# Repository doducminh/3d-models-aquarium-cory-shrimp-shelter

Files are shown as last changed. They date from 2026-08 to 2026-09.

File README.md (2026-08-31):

# Hang trú ẩn cho cá chuột — nửa hang áp mặt kính

Một **nửa hang động** áp thẳng vào mặt kính hồ. Mặt kính làm "thành thứ tư" của
hang, nên nhìn qua kính thấy đúng một mặt cắt hang động — và thấy con cá đang
làm gì bên trong. Toàn thân chôn dưới nền, chỉ **cửa hang và chỏm đá** nhô lên.

In bằng **PETG** (ngâm nước lâu dài; PLA thuỷ phân, giòn dần theo tháng).
**Không một cọng support** — đó là hệ quả hình học, không phải may: toàn vật mô
tả bằng hai trường độ sâu, mặt đá ngoài luôn hướng lên, còn trần hang dựng bằng
hàm khoảng cách nên nghiêng đúng 42° ở mọi chỗ.

> ### Khe hở giữa thân hang và khung mỏng hơn thiết kế — 0,3 mm chứ không phải 2,0
>
> Thiết kế khai khe nhấc **2,0 mm**. Đo lại trên chính sáu file STL trong repo,
> ở đúng tư thế lắp, thì chỗ hẹp nhất chỉ còn:
>
> | bộ | khe thật, chỗ hẹp nhất |
> |---|---|
> | `goc-be-trai/` | +0,61 mm |
> | `goc-be-phai/` | +0,33 mm |
> | `doc-kinh-truoc/` | **−0,18 mm** (17 trên 19 336 đỉnh chạm nhẹ) |
>
> **Cả hai bộ đã in thật và lắp được** — thả thân hang từ trên xuống vào lòng
> khung không cần lực. Nên đây không phải lỗi chặn in, mà là **biên an toàn mỏng
> hơn bảng số nói**: nếu máy bạn in hơi phồng, hoặc bạn in PETG co ngót nhiều,
> thì bộ `doc-kinh-truoc` có thể phải rà nhẹ mép trước khi lắp.
>
> (Bản cảnh báo trước ở chỗ này nói bộ STL "không lắp được" và ghi 208 mm³ đâm
> nhau — số đó đo bằng phép biến đổi lắp sai, đã dựng lại phép đo và không tái
> hiện được; xem HANDOFF điểm mù 96.)

**[Xem mô hình 3D →](viewer/index.html)**

---

## Chọn MỘT thư mục, in CẢ thư mục

Mỗi thư mục là một **bộ hoàn chỉnh**: một thân hang + một khung chắn đất.

| thư mục | đặt ở đâu | thân hang | khung chắn đất | cả bộ |
|---|---|---|---|---|
| **`doc-kinh-truoc/`** | giữa mặt kính trước | 114 × 70 × 48 mm · 41 g · 4h04 | 127 × 60 × 35 mm · 33 g · 3h20 | 74 g · 7h24 |
| **`goc-be-phai/`** | góc bể bên phải, nhìn được từ **hai** mặt kính | 100 × 71 × 48 mm · 33 g · 3h30 | 107 × 60 × 35 mm · 24 g · 2h17 | 57 g · 5h47 |
| **`goc-be-trai/`** | góc bể bên trái, nhìn được từ **hai** mặt kính | 100 × 71 × 48 mm · 33 g · 3h31 | 107 × 60 × 35 mm · 24 g · 2h17 | 57 g · 5h48 |

Bộ góc trái là **ảnh gương** của bộ góc phải — hộp bao trùng khớp tới 0,01 mm ở
cả ba chiều. Chọn theo góc bể bạn định đặt, đừng in cả hai rồi lật.

> **Đừng trộn các thư mục với nhau.** Lòng khung suy ra từ *vết quét* của chính cái thân
> hang cùng bộ; ghép khung của bộ này với thân của bộ kia thì khe nhấc sai và
> hang không rút lên được. Chép **cả thư mục** sang USB là chắc nhất.

`.gcode` slice sẵn cho Elegoo Neptune 4 nằm trong `gcode/<cùng tên thư mục>/`.
`.3mf` đi kèm để mở lại sửa tại chỗ nếu tới nơi mới phát hiện phải chỉnh.

---

## Hai bộ phận làm gì

**Thân hang** — cái hang. In **úp mặt áp kính xuống bàn**; lớp đầu chính là mặt
cắt hang mà người xem nhìn thấy, nên hiệu chuẩn z-offset trước khi in bản thật.

**Khung chắn đất** — một vách mỏng chôn sẵn trong nền, ôm dáng ngầm của hang. Nó
**ở lại** khi nhấc hang lên vệ sinh, nên hạt nền không đổ ập vào chỗ trống. In
**đứng**, vành chân là lớp đầu. Từ bản này nó gánh thêm việc thứ hai: làm **vách
sau** của hang, nhờ đó bụng hang thông suốt và chỗ nằm cho cá rộng gấp 2,6 lần.

### Vành chân là một MÁNG DẰN — phải đổ sỏi vào

Vành chân không phải một tấm phẳng: nó là **máng hở nóc, sâu 18 mm**, chạy dọc
mặt ngoài khung, có một hàng lỗ để nền hai bên nối liền qua.

Lý do nó tồn tại là một con số. Khung nặng 24 g khô, nhưng PETG chỉ nặng hơn nước
27% nên **dưới nước nó chỉ còn 5 gf** — bản đầu tiên đã đổ thật trong hồ, và tính
ra chỉ cần **0,36 gf** đẩy ngang là lật. Nới vành chân rộng ra không cứu được:
cánh tay đòn vốn đã đủ, thứ gần bằng không là **trọng lượng**. Đổ đầy sỏi/nền vào
máng thì lực giữ lên **13 gf**, gấp ba, và trọng tâm hạ từ 15,3 xuống 12,3 mm.

Máng nằm **hoàn toàn bên trong** hình bao cũ — bề sâu vẫn đúng 59,8 mm như bản đã
in vừa chỗ, không phải đo lại gì.

## Cài đặt in

Vòi **0,4** · lớp **0,2** · **PETG** · **không support** (đo được 0% trong cả sáu
file gcode) · **brim 5 mm** cho cả hai chi tiết — đã khai sẵn trong `.gcode`.

Brim không phải cho chắc ăn thừa. Thân hang có lớp đầu là một **vành rộng 9 mm,
chu vi ~330 mm**: nó không chênh vênh và không lật, nó **bong mép** — mà mép ấy
chính là mặt người xem nhìn vào. Khung thì là một bức tường cao gấp 12 lần bề dày,
dài hơn 200 mm, cong vênh theo chiều dài khi PETG co ngót.

Cả hai chi tiết **đã ở đúng tư thế in trong file** — đừng để slicer tự xoay, và
đừng in hai chi tiết cùng một tư thế.

## Lắp

1. **Rải một lớp nền mỏng xuống trước**, rồi mới đặt khung và ấn cho vành chân
   lún vào. Đặt khung lên mặt kính trơn thì nó chưa có gì giữ.
2. **Đổ sỏi/nền đầy máng dằn** ở vành chân — đây là bước dễ quên nhất và là bước
   quyết định khung có đứng vững không.
3. Lấp nền quanh khung, ngoài khung, cho ngập qua máng.
4. Thả **thân hang** thẳng từ trên xuống vào lòng khung — khe hở 2 mm, không cần lực.
5. Vun nền cho ngập tới chân cửa hang; ngưỡng cửa cao hơn mặt nền 6 mm nên hạt
   không tràn vào.

**Lúc nhấc hang ra vệ sinh:** giữ một tay lên mép khung, tay kia rút hang thẳng
lên. Ma sát khi hang trượt qua khe 2 mm là đủ để kéo theo cả cái khung.

Ngâm nước **48 giờ** xả mùi trước khi thả vào hồ đang có cá.

---

## Xem trước

`viewer/index.html` — mở thẳng bằng trình duyệt, không cần máy chủ web. Trang
dựng hình bằng JS nên chỉnh được kiểu hang, hướng cửa, cỡ in… và xem số đo đổi
theo ngay.

## Cửa hang KHÔNG chặn được cá lớn — đo rồi, và nó là giới hạn cứng

Nếu bạn định dùng hang này để cá nhỏ trốn một con cá lớn hơn, đọc mục này trước.

Cửa cao 22,4 mm. Nó **không** hạ xuống được bao nhiêu, vì chính con cá chuột đặt
ra sàn: thân nó cao 14,4 mm và phải có 2 mm khe mỗi bên — gai ngực nó **khoá lại
khi hoảng**, kẹt cửa là chết cá. Sàn cứng vì thế là **18,4 mm**, và toàn bộ chỗ
co giãn của cửa chỉ là 22,4 → 18,9 mm.

Con betta trong hồ thử nghiệm đo được **cao thân 15,0 mm** (cụp vây). Nó mỏng hơn
cả cái sàn 18,4 mm, nên **không tồn tại cái cửa nào vừa cho cá chuột qua vừa chặn
nó** — hai loài chỉ cách nhau 0,6 mm bề cao thân. Thu nhỏ cửa là ngõ cụt, không
phải chuyện tinh chỉnh.

Muốn chặn thì phải chặn bằng **hình thái cửa** chứ không phải cỡ cửa: cá chuột là
cá đáy, chui khe là bản năng; cá tầng giữa vây dài thì tránh ống dài tối có khúc
quẹo. Viewer có sẵn bốn kiểu cửa để xem — `sau` (rèm đá che), `ben` (khe ngang
xuyên sườn), `duoi` (cửa quay xuống nền). **Các file STL ở đây đều là kiểu `kinh`
(cửa nhìn thẳng), tức KHÔNG có hàng rào nào.**

## Trạng thái

✅ **Đã in thật bộ `doc-kinh-truoc/` và bộ `goc-be-phai/`** — lắp vào hồ đạt, chủ
dự án nghiệm thu ổn. Đó là hai bộ đã đi hết vòng: thiết kế → in → ướm vào chỗ thật.

⚠️ **Khung của cả ba bộ đã được dựng lại** sau khi bản in đầu **đổ trong hồ**: vành
chân giờ là máng dằn (mục trên). Thân hang **không đổi một milimét nào** — file
`than-hang.stl` của bạn vẫn dùng được, chỉ cần in lại `khung-chan-dat.stl`.
Máng dằn thì mới, **chưa qua bản in thật**.

⚠️ Bộ `goc-be-trai/` **chưa in** — nhưng nó là ảnh gương đúng nghĩa của bộ góc
phải đã in đạt, dựng từ cùng bộ script, cùng cỡ, cùng seed.

Bảng số trong README này là số đo trên mô hình và trên gcode, không phải cân đo
vật in ra; lệch vài phần trăm khối lượng là bình thường.

---

## Bản quyền

Cả sáu file đều mang dấu **`doducminh`** khắc chìm trên vật. Trên thân hang
dấu nằm ở mặt áp kính và khắc **soi gương** — đọc đúng chiều khi nhìn từ ngoài
hồ vào.

Giấy phép: **CC BY-NC-SA 4.0** cho file thiết kế.

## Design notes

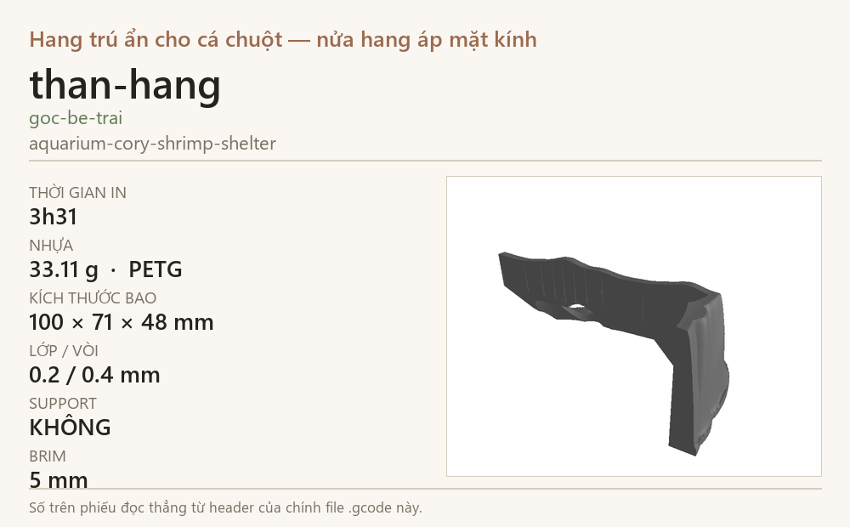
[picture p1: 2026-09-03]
gcode/goc-be-trai/than-hang.png

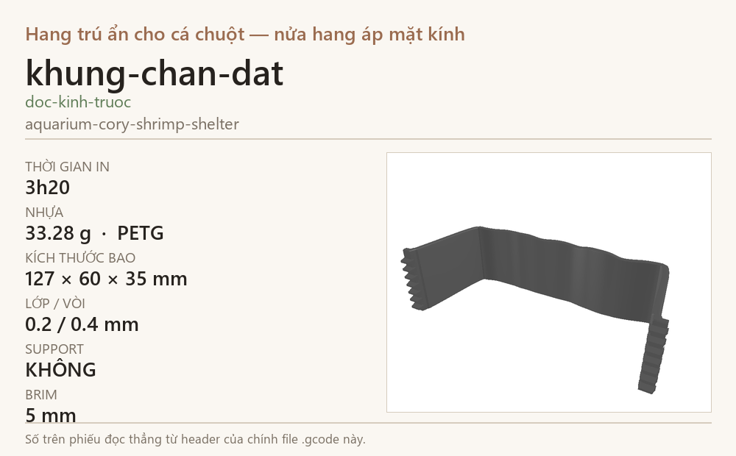
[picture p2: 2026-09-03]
gcode/doc-kinh-truoc/khung-chan-dat.png

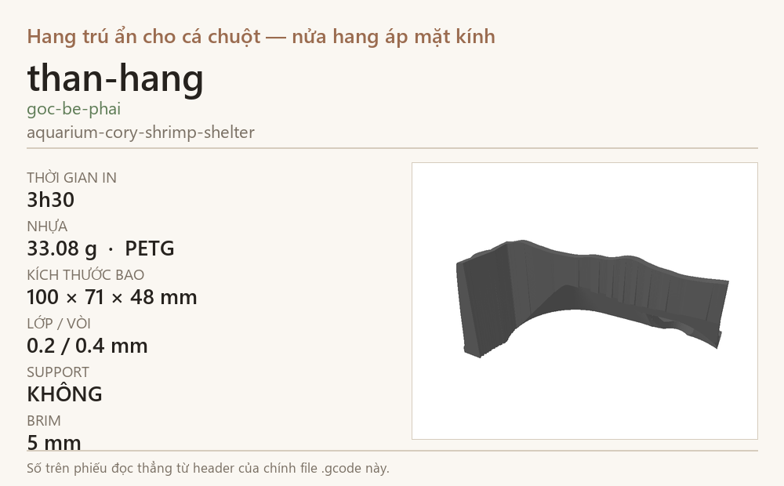
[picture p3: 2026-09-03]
gcode/goc-be-phai/than-hang.png

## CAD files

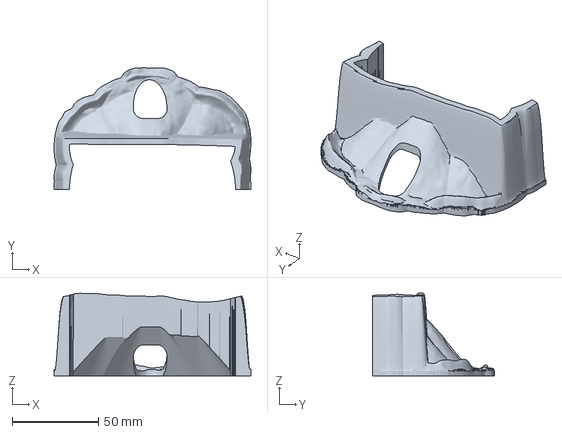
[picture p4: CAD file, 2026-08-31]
gcode/doc-kinh-truoc/than-hang.3mf
114.0 x 70.3 x 47.8 mm

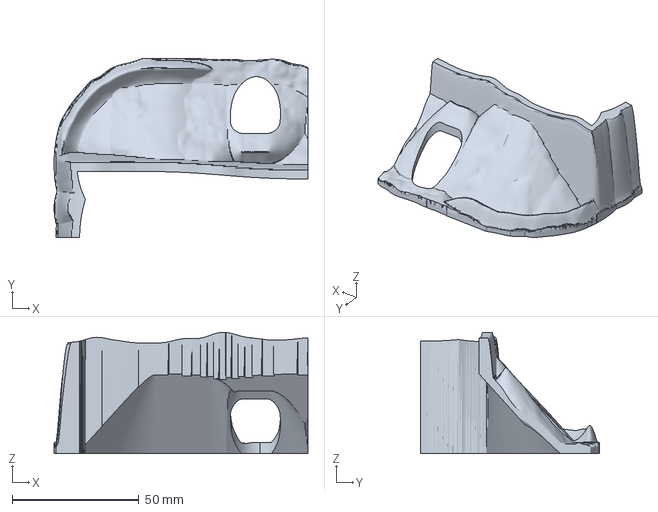
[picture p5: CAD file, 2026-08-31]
gcode/goc-be-phai/than-hang.3mf
100.0 x 70.6 x 47.8 mm

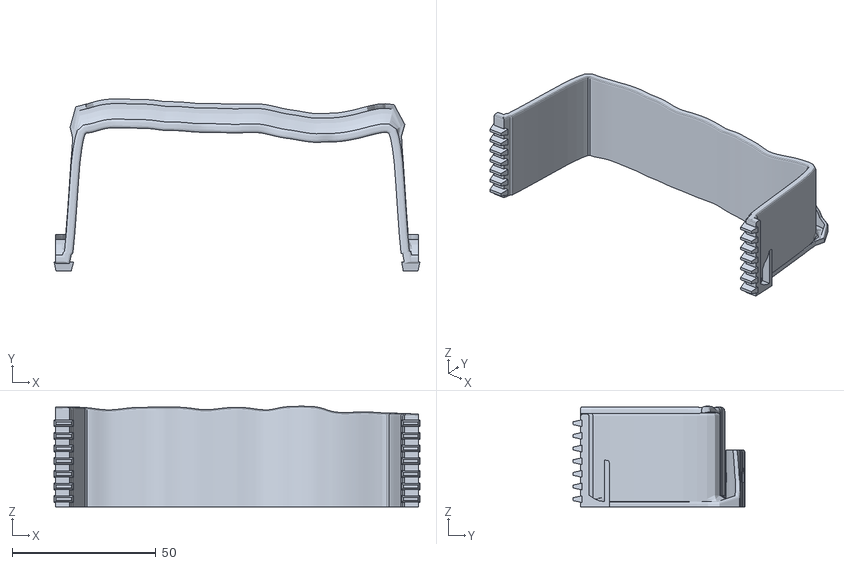
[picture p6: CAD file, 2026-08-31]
stl/doc-kinh-truoc/khung-chan-dat.stl
127.2 x 59.8 x 34.9

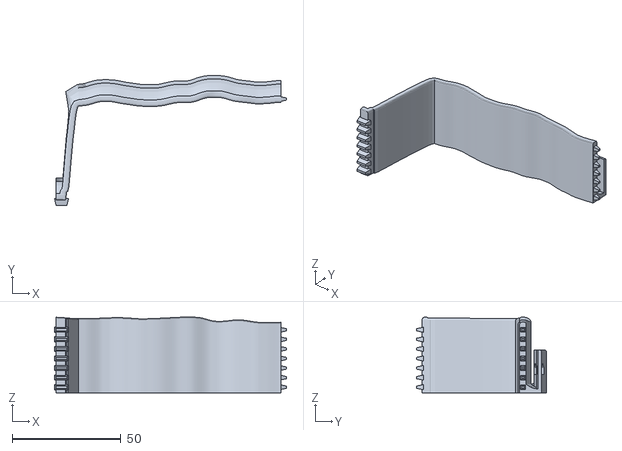
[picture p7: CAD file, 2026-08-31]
stl/goc-be-phai/khung-chan-dat.stl
106.7 x 59.8 x 34.9

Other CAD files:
gcode/goc-be-trai/than-hang.3mf
stl/goc-be-trai/khung-chan-dat.stl
gcode/doc-kinh-truoc/khung-chan-dat.3mf
gcode/goc-be-phai/khung-chan-dat.3mf
gcode/goc-be-trai/khung-chan-dat.3mf
stl/doc-kinh-truoc/than-hang.stl
stl/goc-be-phai/than-hang.stl
stl/goc-be-trai/than-hang.stl

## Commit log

2026-08-30 File thanh pham: 3 bo STL + gcode, viewer, README, LICENSE
    Hang tru an nua-hang ap mat kinh cho ca chuot. Ba cho dat, moi cho mot
    thu muc tron bo (than hang + khung chan dat): doc kinh truoc, goc be
    phai, goc be trai.
    Hai bo `doc-kinh-truoc/` va `goc-be-phai/` DA IN THAT va lap vao ho dat.
    Bo `goc-be-trai/` la anh guong cua bo goc phai — hop bao trung khop toi
    0,01 mm o ca ba chieu.
    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
    [khung-chan-dat.3mf, khung-chan-dat.stl, than-hang.3mf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]
2026-08-31 CANH BAO: bo STL hien tai khong lap duoc — tam dung in
    Than hang va khung chan dat trong cung mot thu muc khong long vao nhau duoc.
    Do tren chinh sau file trong repo: than cua goc-be-phai chi long khit vao khung
    cua goc-be-trai va nguoc lai; ban doc-kinh-truoc dam nhau 208 mm3 thay vi khe
    2,0 mm. Hai bo dung xuat mesh theo hai quy uoc tay nguoc nhau.
    Trang xem 3D van dung — no dung hinh bang JS, khong doc STL.
2026-08-31 Khung chan dat: vanh chan thanh MANG DAN — ban in dau do trong ho
    Ban in that cua khung khong giu duoc thang bang khi cho vao ho va khi rut
    than hang ra. Nguyen nhan do duoc: PETG 1,27 g/cm3 chi nang hon nuoc 27%,
    nen khung 20,9 g kho chi con 4,5 gf DUOI NUOC — va chi can 0,36 gf day
    ngang la lat khi no dung tren nen hat.
    Ne rong vanh chan khong cuu duoc: canh tay don von da 17 mm, thu gan bang
    khong la TRONG LUONG (day vanh chan 1,8 -> 8 mm chi duoc 3,4 -> 4,6 gf).
    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
    [khung-chan-dat.3mf, khung-chan-dat.stl, than-hang.3mf]
2026-08-31 Do duoc con ca lon: 15mm — cua hang KHONG chan duoc no, va khong the chan
    Chu du an bao con betta boi ra vao hang tu nhien. Da do: cao than 15,0 mm
    (cup vay). So nay treo [todo] tu dau du an va chay tam bang 25 — chinh con
    25 ay lam moi bang kiem bao "cua vom kin CHAN duoc ca lon" suot 15 phien.
    No chua bao gio chan.
    Cua khong the nho hon 18,4 mm vi CA CHUOT phai lot: than cao 14,4 + 2 mm
    khe moi ben (gai nguc khoa khi hoang, ket cua la chet ca). Hai loai cach
    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
2026-08-31 Go canh bao "khong lap duoc" — do lai khong tai hien duoc
    Canh bao dan hom nay noi bo STL khong lap duoc va ghi 208 mm3 dam nhau o
    ban doc-kinh-truoc. Dung lai phep do thi:
    doc-kinh-truoc giao nhau 0,2 mm3 (canh bao noi 208)
    goc-be-phai giao nhau 0,0
    goc-be-trai giao nhau 0,0
    Va lap luan "than goc-be-phai chi long vao khung goc-be-trai" khong dung:
    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
2026-09-03 Phieu anh cho moi file .gcode
    Nhung thumbnail vao chinh gcode (khoi `;gimage:`/`;simage:` cho man hinh Elegoo
    Neptune, va khoi `; thumbnail` chuan PrusaSlicer/Klipper), va them mot file .png
    cung ten nam canh de xem tren may tinh.
    Tren USB thi moi thu chi con la mot cai ten khong dau — phieu nay tra loi "day la
    cai gi": ten chi tiet, ten du an, thoi gian in, so gam, vat lieu, be day lop,
    support, brim, va hop bao THAT cua chi tiet.
    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
